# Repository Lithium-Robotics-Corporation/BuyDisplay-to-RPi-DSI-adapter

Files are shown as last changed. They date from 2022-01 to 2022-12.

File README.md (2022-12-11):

# Buydisplay Adapter Board
### To be used with: https://www.buydisplay.com/7-84-inch-bar-style-ips-tft-iot-lcd-display-1280x400-mipi-for-car-monitor

#### This PCB intended to allow you to connect the above MIPI DSI 2-lane LCD to a Raspberry Pi via the common 22-pin RPi DSI connector. 
#### Note that this PCB also contains an 18V backlight boost converter for driving the display's backlight array.

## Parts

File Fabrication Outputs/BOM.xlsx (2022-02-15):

Qty | Value | Device | Package | Manufacturer | Part Number | Parts | Description
3 | 0.1uF | CAPACITOR.0603 | 0603 | KEMET | C0603C104K5RACAUTO7411 | C1, C3, C7
1 | 100R | RESISTOR.0603 | 0603 | TE Connectivity | CRGP0603F100R | R1
3 | 10k | RESISTOR.0603 | 0603 | ROHM | SDR03EZPF1002 | R2, R4, R7
1 | 10uF | CAPACITOR.0603 | 0603 | Murata | GRM188R61E106MA73J | C4
2 | 10uF_25V | CAPACITOR.0805 | 0805 | Taiyo Yuden | TMK212BBJ106MGHT | C5, C6
1 | 2.4uH | Inductor |  | Bourns | SDR0603-2R5ML | L1
1 | 170k | RESISTOR.0603 | 0603 | Bourns | CR0603-FX-1693ELF | R6
1 | 1k | RESISTOR.0603 | 0603 | ROHM | ESR03EZPJ102 | R5
1 | 1uF | CAPACITOR.0603 | 0603 | Taiyo Yuden | TMK107BJ105KA8T | C2
1 | 330R | RESISTOR.0603 | 0603 | ROHM | SFR03EZPF3300 | R8
1 | 47.5k | RESISTOR.0603 | 0603 | ROHM | SFR03EZPF4752 | R3
1 |  | 54548-2271 | 545482271 | Molex | 545482271 | J3 | FFC & FPC Connectors 0.5 FPC ZIF Hsg Assy ssy 22Ckt EmbsTp Pkg
1 |  | 62684-401100AHLF | 62684401100AHLF | Amphenol | 62684401100AHLF | J1 | FFC & FPC Connectors 62684-401100AHLF-OPUD
1 |  | LT8336HV#PBF | LT8336HVPBF | Analog Devices | LT8336HV#PBF | IC1 | Switching Voltage Regulators 40V, 2.5A Low IQ Sync Step-Up Silent Sw
1 | Red | LED.0603 | 0603.LED | ROHM | SML-D12U8WT86C | D1
1 |  | SFV6R-3STE1HLF | SFV6R3STE1HLF | Amphenol | SFV6R-3STE1HLF | J2 | FFC & FPC Connectors 6P R/A SMT FFC/FPC 0.5mm CONT SPACING

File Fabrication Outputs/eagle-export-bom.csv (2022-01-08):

Qty | Value | Device | Package | Parts | Description | DESCRIPTION | HEIGHT | MANUFACTURER_NAME | MANUFACTURER_PART_NUMBER | MOUSER_PART_NUMBER | MOUSER_PRICE-STOCK | POPULARITY
1 |  | PINHD-1X2 | 1X02 | JP3 | PIN HEADER |  |  |  |  |  |  | 98
2 |  | PINHD-1X3 | 1X03 | JP1, JP2 | PIN HEADER |  |  |  |  |  |  | 92
1 |  | TAC_SWITCHPTH | TACTILE-PTH | S7 | Momentary Switch
4 |  | TESTPOINTROUND1MM | TESTPOINT_ROUND_1MM | TP1, TP2, TP3, TP4 | Test Point
3 | 0.1uF | CAPACITOR.0603 | 0603 | C1, C3, C7
1 | 100R | RESISTOR.0603 | 0603 | R1
3 | 10k | RESISTOR.0603 | 0603 | R2, R4, R7
1 | 10uF | CAPACITOR.0603 | 0603 | C4
2 | 10uF_25V | CAPACITOR.0805 | 0805 | C5, C6
1 | 1235AS-H-2R4M=P3 | 1235AS-H-2R4M=P3 | 1235ASH100MP3 | L1 | DEM4518C Series Inductor 2.4uH +/-20% 1818 (4745) | DEM4518C Series Inductor 2.4uH +/-20% 1818 (4745) | 2mm | Murata Electronics | 1235AS-H-2R4M=P3 | 81-1235AS-H-2R4MP3 | https://www.mouser.com/Search/Refine.aspx?Keyword=81-1235AS-H-2R4MP3
1 | 170k | RESISTOR.0603 | 0603 | R6
1 | 1k | RESISTOR.0603 | 0603 | R5
1 | 1uF | CAPACITOR.0603 | 0603 | C2
1 | 330R | RESISTOR.0603 | 0603 | R8
1 | 47.5k | RESISTOR.0603 | 0603 | R3
1 | 54548-2271 | 54548-2271 | 545482271 | J3 | FFC & FPC Connectors 0.5 FPC ZIF Hsg Assy ssy 22Ckt EmbsTp Pkg | FFC & FPC Connectors 0.5 FPC ZIF Hsg Assy ssy 22Ckt EmbsTp Pkg | 1mm | Molex | 54548-2271 | 538-54548-2271 | https://www.mouser.co.uk/ProductDetail/Molex/54548-2271?qs=qM7ngqbhX5X3ZiWzRWv9wA%3D%3D
1 | 62684-401100AHLF | 62684-401100AHLF | 62684401100AHLF | J1 | FFC & FPC Connectors 62684-401100AHLF-OPUD | FFC & FPC Connectors 62684-401100AHLF-OPUD | 2.3mm | Amphenol | 62684-401100AHLF | 649-62684-401100AHLF | https://www.mouser.co.uk/ProductDetail/Amphenol-FCI/62684-401100AHLF?qs=6gcroF09reXdRG%252BmgzzG%2FQ%3D%3D
1 | LT8336HV#PBF | LT8336HV#PBF | LT8336HVPBF | IC1 | Switching Voltage Regulators 40V, 2.5A Low IQ Sync Step-Up Silent Sw | Switching Voltage Regulators 40V, 2.5A Low IQ Sync Step-Up Silent Sw | 1.03mm | Analog Devices | LT8336HV#PBF | 584-LT8336HV#PBF | https://www.mouser.co.uk/ProductDetail/Analog-Devices/LT8336HVPBF?qs=bAKSY%2FctAC6ZfL1l2LeQJQ%3D%3D
1 | Red | LED.0603 | 0603.LED | D1
1 | SFV6R-3STE1HLF | SFV6R-3STE1HLF | SFV6R3STE1HLF | J2 | FFC & FPC Connectors 6P R/A SMT FFC/FPC 0.5mm CONT SPACING | FFC & FPC Connectors 6P R/A SMT FFC/FPC 0.5mm CONT SPACING | 2mm | Amphenol | SFV6R-3STE1HLF | 649-SFV6R-3STE1HLF | https://www.mouser.co.uk/ProductDetail/Amphenol-FCI/SFV6R-3STE1HLF?qs=pLQRQR43dtql2xROP1LV5w%3D%3D

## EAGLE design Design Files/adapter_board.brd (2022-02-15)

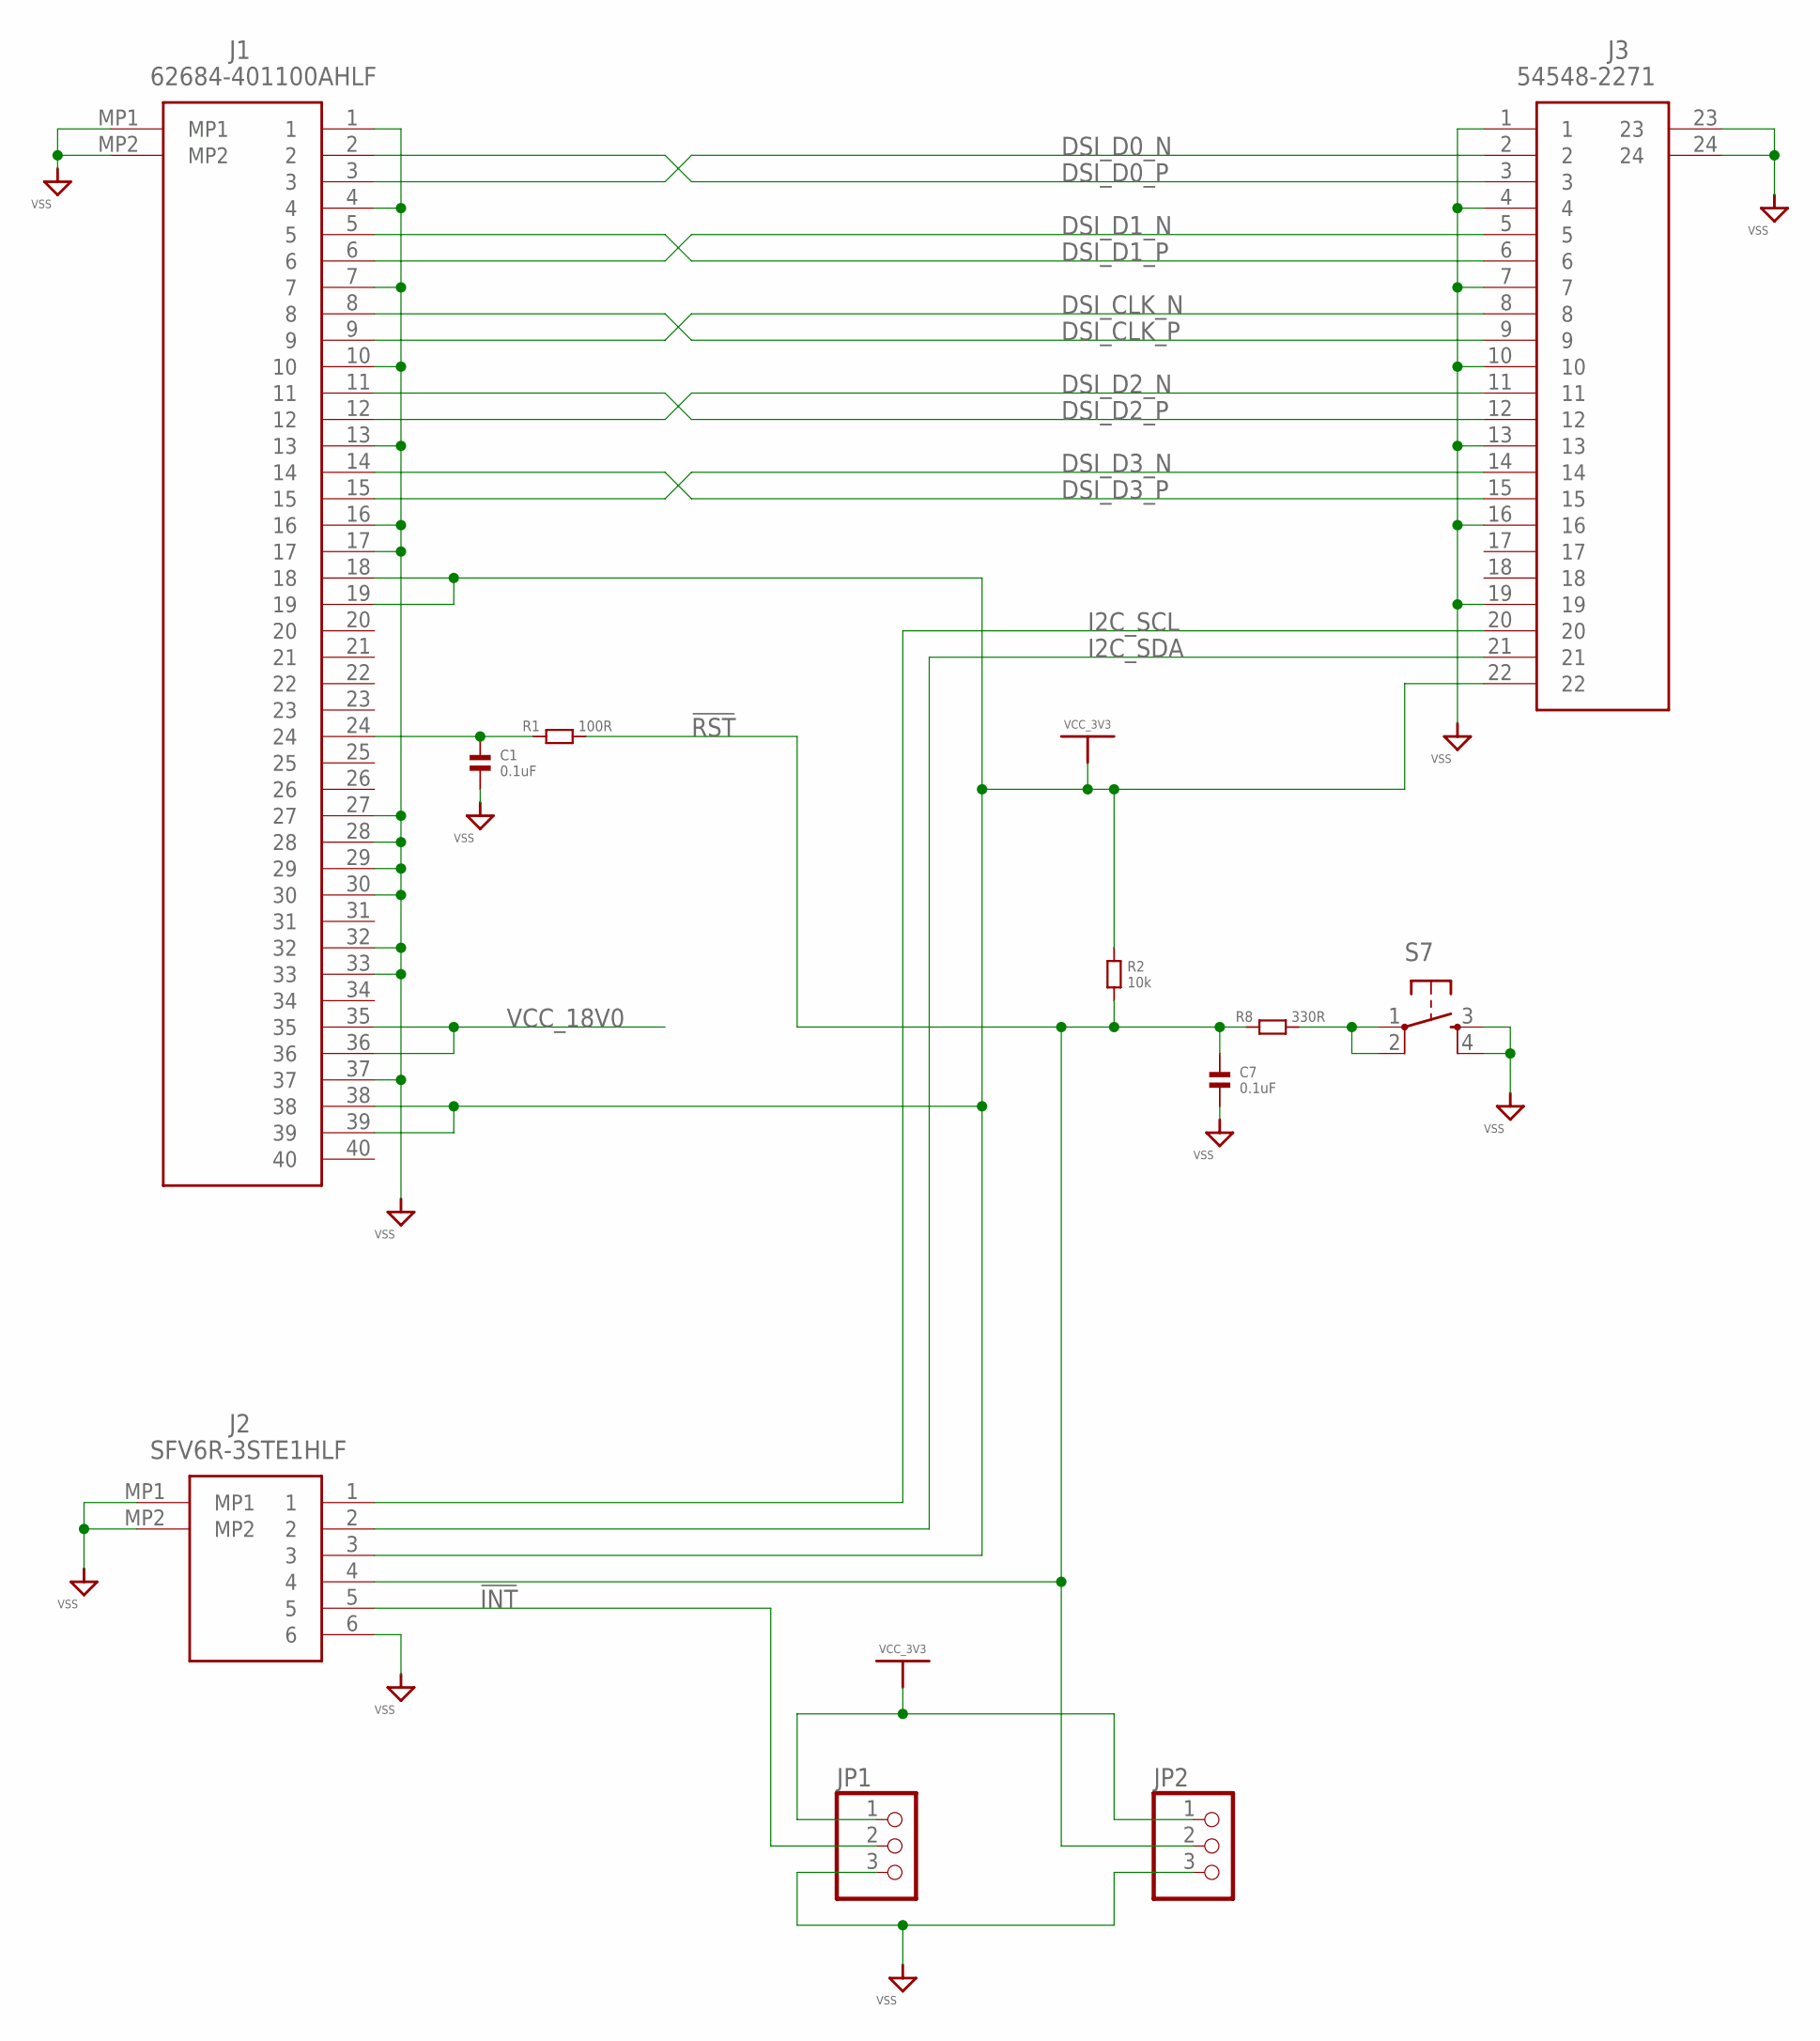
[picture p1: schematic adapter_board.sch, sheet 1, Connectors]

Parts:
C1, C7: 0.1uF; 0603
J1: 62684-401100AHLF; 62684401100AHLF
J2: SFV6R-3STE1HLF; SFV6R3STE1HLF
J3: 54548-2271; 545482271
JP1, JP2: PINHD-1X3; 1X03
R1: 100R; 0603
R2: 10k; 0603
R8: 330R; 0603
S7: TAC_SWITCHPTH; TACTILE-PTH

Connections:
!INT: J2.5, JP1.2
!RST: C7.1, J2.4, JP2.2, R1.2, R2.2, R8.1
DSI_CLK_N: J1.9, J3.8
DSI_CLK_P: J1.8, J3.9
DSI_D0_N: J1.3, J3.2
DSI_D0_P: J1.2, J3.3
DSI_D1_N: J1.6, J3.5
DSI_D1_P: J1.5, J3.6
DSI_D2_N: J1.12, J3.11
DSI_D2_P: J1.11, J3.12
DSI_D3_N: J1.15, J3.14
DSI_D3_P: J1.14, J3.15
I2C_SCL: J2.1, J3.20
I2C_SDA: J2.2, J3.21
unnamed: C1.1, J1.24, R1.1
unnamed: R8.2, S7.1, S7.2
VCC_3V3: J1.18, J1.19, J1.38, J1.39, J2.3, J3.22, JP1.1, JP2.1, R2.1
VCC_18V0: J1.35, J1.36; also elsewhere on the board
VSS: C1.2, C7.2, J1.1, J1.4, J1.7, J1.10, J1.13, J1.16, J1.17, J1.27, J1.28, J1.29, J1.30, J1.32, J1.33, J1.37, J1.MP1, J1.MP2, J2.6, J2.MP1, J2.MP2, J3.1, J3.4, J3.7, J3.10, J3.13, J3.16, J3.19, J3.23, J3.24, JP1.3, JP2.3, S7.3, S7.4; also elsewhere on the board

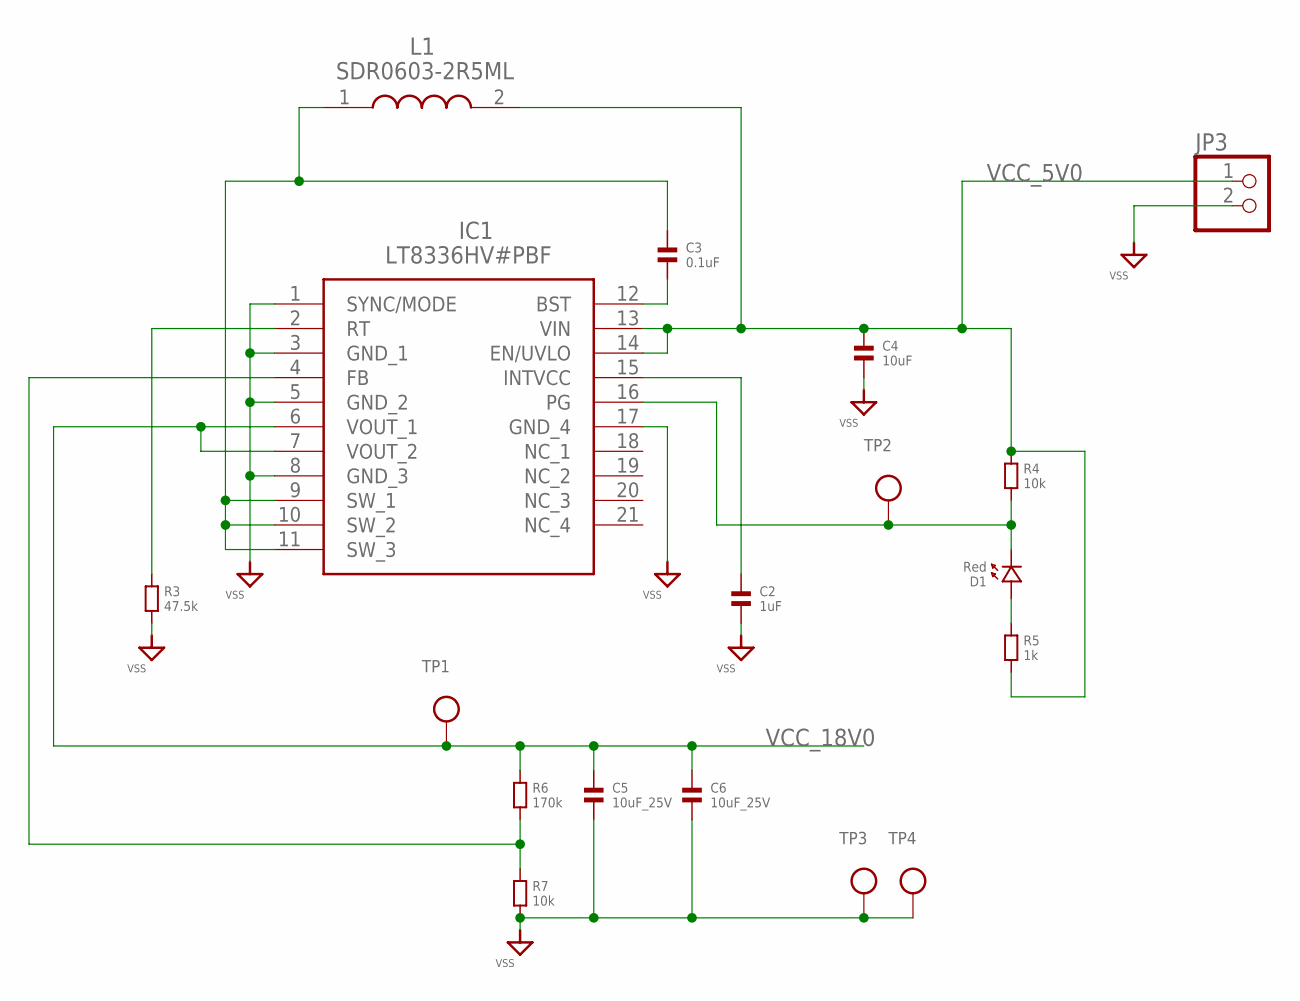
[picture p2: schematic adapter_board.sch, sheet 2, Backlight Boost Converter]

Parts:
C2: 1uF; 0603
C3: 0.1uF; 0603
C4: 10uF; 0603
C5, C6: 10uF_25V; 0805
D1: Red; 0603.LED
IC1: LT8336HV#PBF; LT8336HVPBF
JP3: PINHD-1X2; 1X02
L1: SDR0603-2R5ML; SDR06032R5ML
R3: 47.5k; 0603
R4, R7: 10k; 0603
R5: 1k; 0603
R6: 170k; 0603
TP1, TP2, TP3, TP4: TESTPOINTROUND1MM; TESTPOINT_ROUND_1MM

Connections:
unnamed: C2.1, IC1.15 (INTVCC)
unnamed: IC1.2 (RT), R3.1
unnamed: C3.1, IC1.9 (SW_1), IC1.10 (SW_2), IC1.11 (SW_3), L1.1
unnamed: C3.2, IC1.12 (BST)
unnamed: D1.P$2 (2), IC1.16 (PG), R4.2, TP2.P$1
unnamed: D1.P$1 (1), R5.1
unnamed: IC1.4 (FB), R6.2, R7.1
VCC_5V0: C4.1, IC1.13 (VIN), IC1.14 (EN/UVLO), JP3.1, L1.2, R4.1, R5.2
VCC_18V0: C5.1, C6.1, IC1.6 (VOUT_1), IC1.7 (VOUT_2), R6.1, TP1.P$1; also elsewhere on the board
VSS: C2.2, C4.2, C5.2, C6.2, IC1.1 (SYNC/MODE), IC1.3 (GND_1), IC1.5 (GND_2), IC1.8 (GND_3), IC1.17 (GND_4), JP3.2, R3.2, R7.2, TP3.P$1, TP4.P$1; also elsewhere on the board

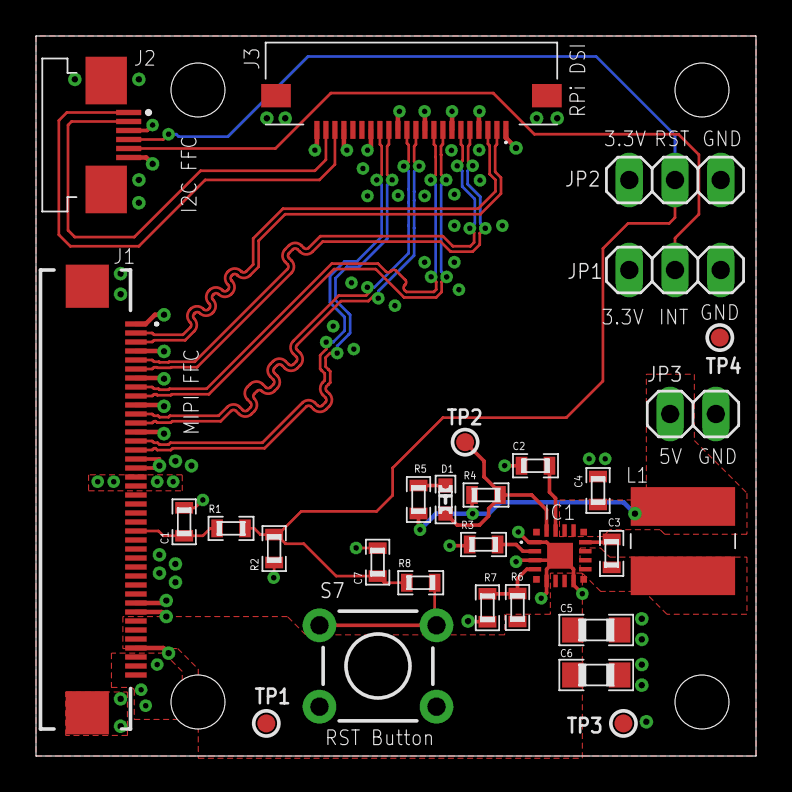
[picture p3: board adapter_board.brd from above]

Board: 4 copper layers, 40.0 x 40.0 mm, 29 parts (0 on the bottom side), 27 nets.

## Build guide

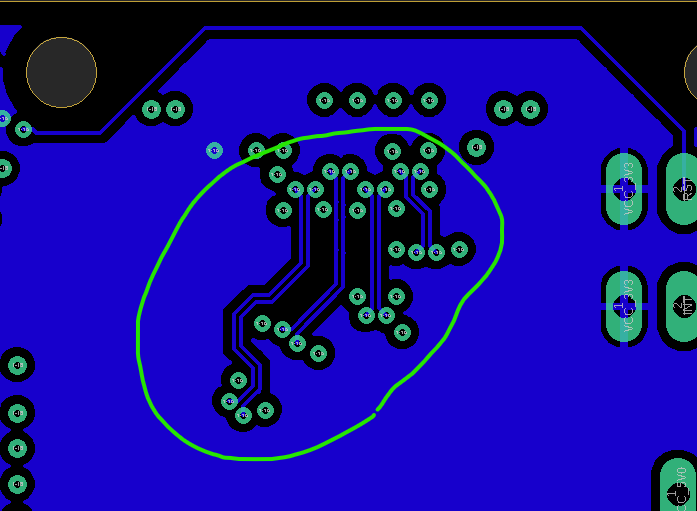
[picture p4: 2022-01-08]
Fabrication Outputs/Impedance Control/l4.png

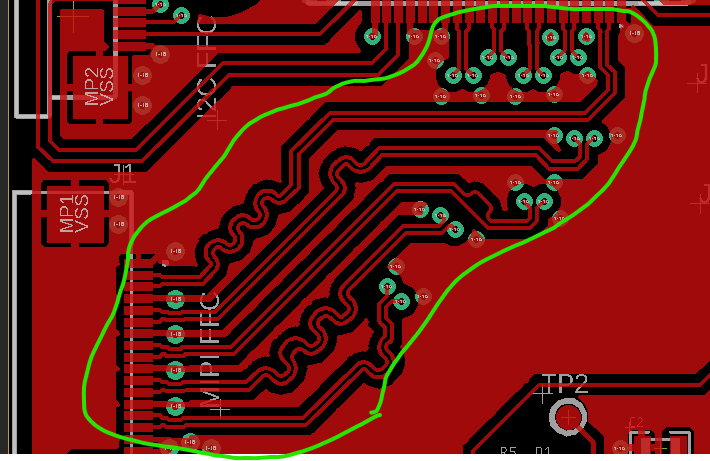
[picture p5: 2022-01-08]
Fabrication Outputs/Impedance Control/l1.png

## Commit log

2022-01-07 Almost done with schematic.
    [adapter_board.sch]
2022-01-08 Finished backlight boost converter schematic
    [adapter_board.sch]
2022-01-08 Finished PCB. Generated fabrication data.
    [adapter_board.brd, adapter_board.sch]
2022-01-08 Changed inductor L1.
    [BOM.xlsx, adapter_board.brd, adapter_board.sch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]
2022-01-08 Changed min width/spacing to 6/6. Length matched DSI traces.
    [adapter_board.brd, adapter_board.sch]
2022-02-14 Changed PGOOD LED to 5V rail.
    [BOM.xlsx, adapter_board.brd, adapter_board.sch]
2022-02-15 Changed D1 back to red.
    [BOM.xlsx, adapter_board.brd, adapter_board.sch]
2022-12-11 Cleaned up files. Updated README.
    [adapter_board.brd, adapter_board.sch]

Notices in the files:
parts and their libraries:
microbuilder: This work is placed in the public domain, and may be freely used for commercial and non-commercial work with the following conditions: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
